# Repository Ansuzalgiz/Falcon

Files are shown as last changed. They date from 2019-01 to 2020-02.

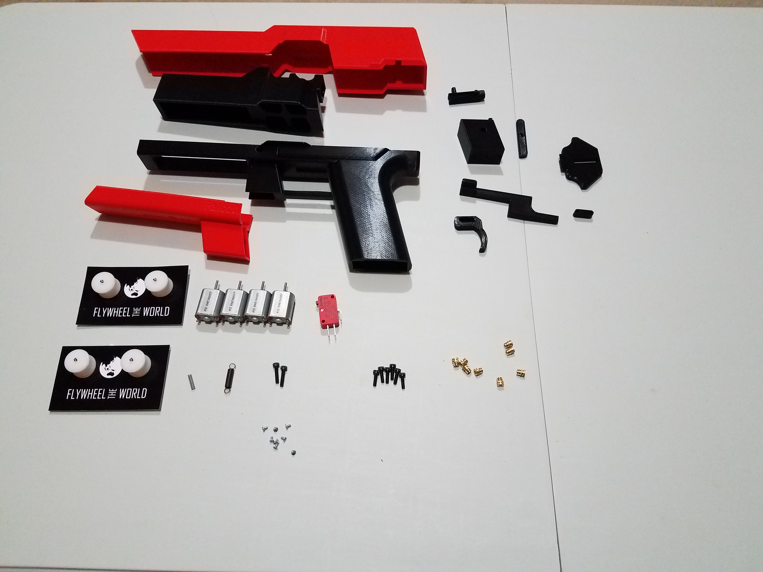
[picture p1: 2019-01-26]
Images/AllParts.jpg

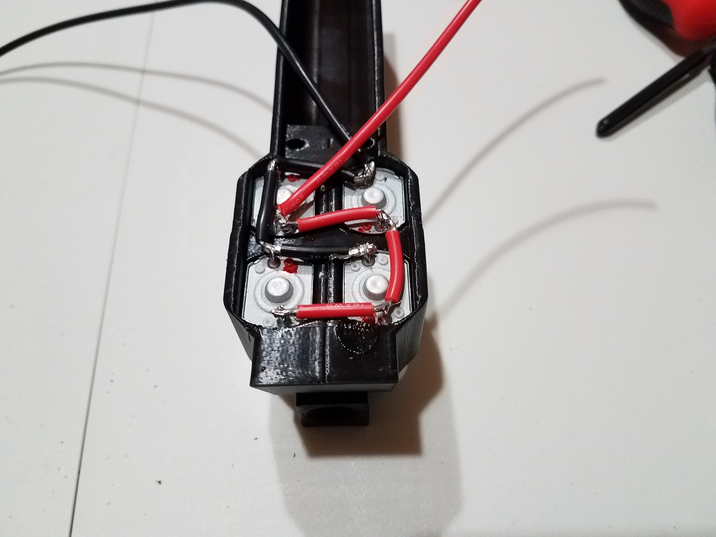
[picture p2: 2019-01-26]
Images/Wiring1.jpg

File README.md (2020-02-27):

# Falcon

The Falcon is a 3D printed semiautomatic Nerf pistol using Talon magazines.

# Features
- Dual stage flywheels using FTW flywheels
- Single trigger design
- Talon magazine compatibility
- Ambidextrous thumb actuated magazine release
- Optional builtin HOLDster mount

# Video Review

[Review by Drac](https://www.youtube.com/watch?v=akCXBWrKhHA)

# Online Availability
[Sold online on Etsy](https://www.etsy.com/shop/ansuzalgiz)

# Required Parts

|Part |Quantity  |Description |
|---|---|---|
|MTB Honeybadgers |4 |Flywheel Motors [Purchase link](https://outofdarts.com/collections/motors/products/mtb-honey-badger-130-motor-for-nerf-blasters) |
|FTW Flywheels |2 |Two sets of flywheels [Purchase link](https://blogderrikksun.com/product/mini-flywheels-set-for-pigeon-and-other-ftw-blasters/) |
|21A Microswitch  |1 |Flywheel switch [Purchase link](https://outofdarts.com/collections/parts/products/21a-microswitch-button-clone)|
|Heat set threaded inserts| 8 | To hold in screws (McMaster 94180A333 for 100) |
|Compression Spring | 1 | For magazine release (McMaster 9657K266 for 6) |
|Compression Spring | 1 | For trigger (McMaster 9657k297 for 12) |
|M3x14 Socket head screw  | 2 | For attaching PusherMount to lower receiver |
|M3x10 Socket head screws | 6 | For attaching all other parts |
|M2x4 screws | 8 | For motors |
|Silicone grease | | For trigger mechanism |
|M5x.08 tap | 1 | For finishing the HOLDster top cover for screwing in the Fidlock magnets |
|HOLDster Fidlock magnets | 1 pair | For HOLDster support [Purchase link](https://outofdarts.com/products/holdster-magnets)| 

# Printing Parameters
Prototypes were printed using these parameters:
- PLA
- 300 micron layer height
- .4mm nozzle
- No supports

# Contributing
The project was designed using Fusion 360, under their hobbyist license. After updating the design, export the changed STEP and STL files and use software like MeshMixer or 3D Builder to orient the STLs for printing.

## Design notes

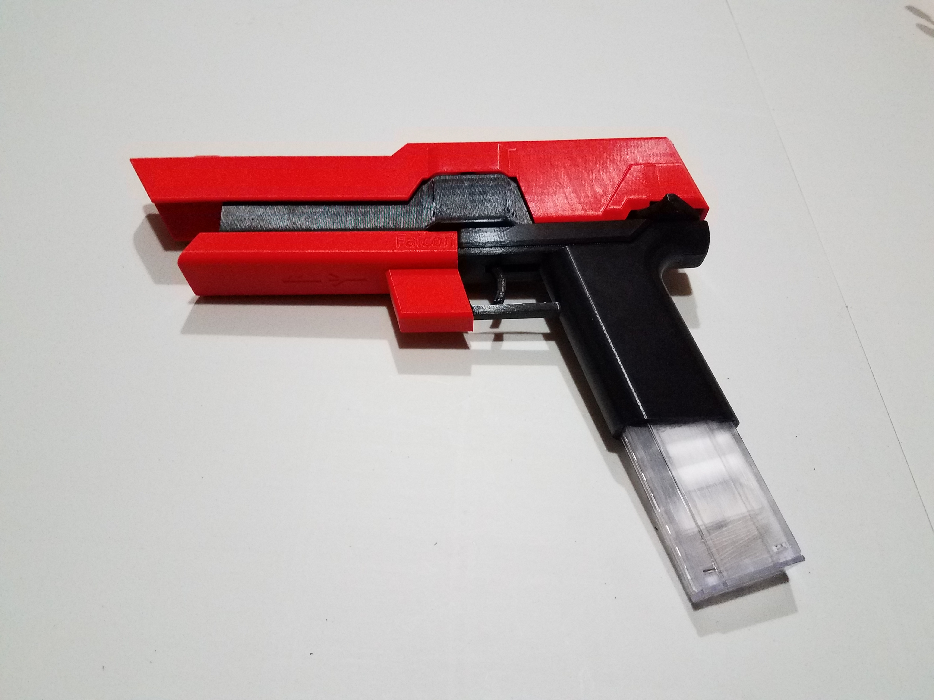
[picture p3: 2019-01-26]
Images/Finished.jpg

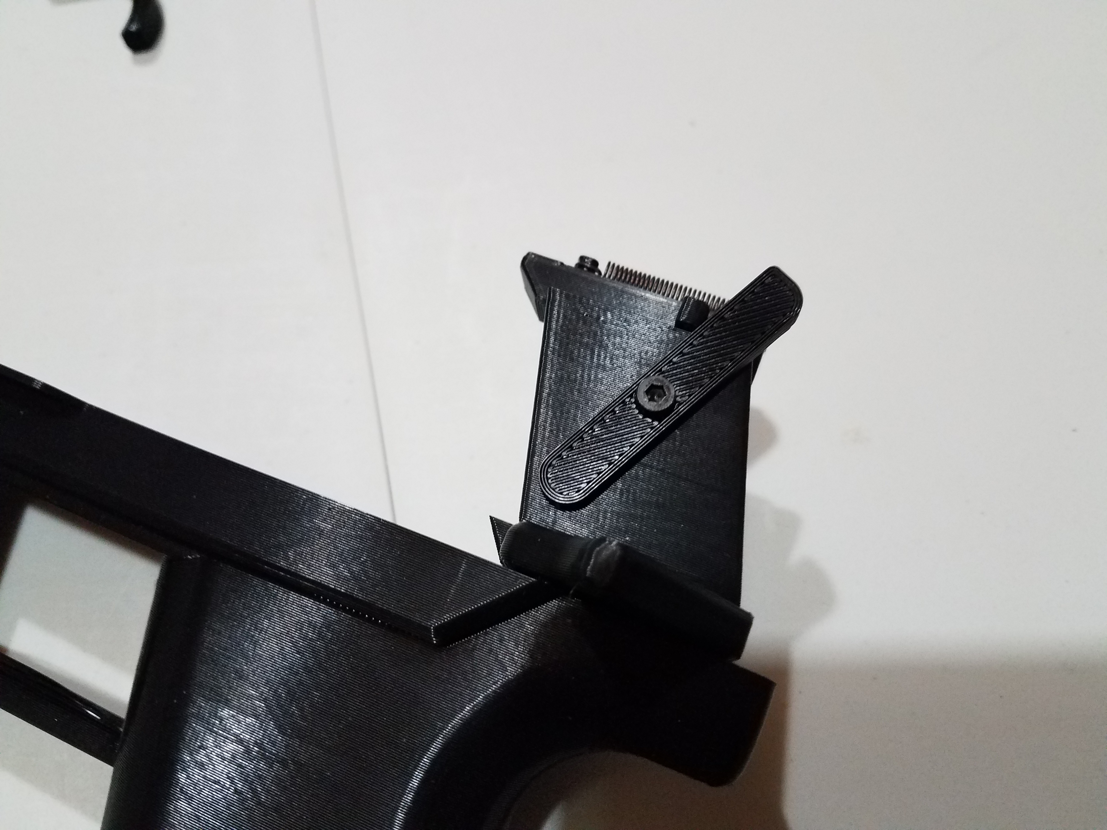
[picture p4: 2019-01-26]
Images/Pusher3.jpg

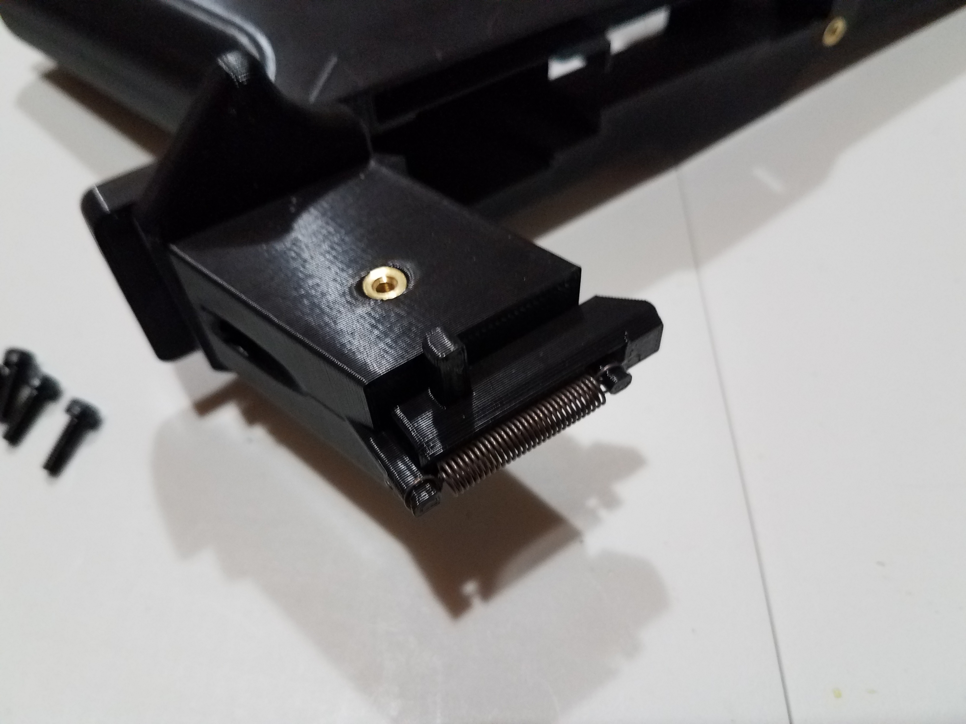
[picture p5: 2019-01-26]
Images/Pusher2.jpg

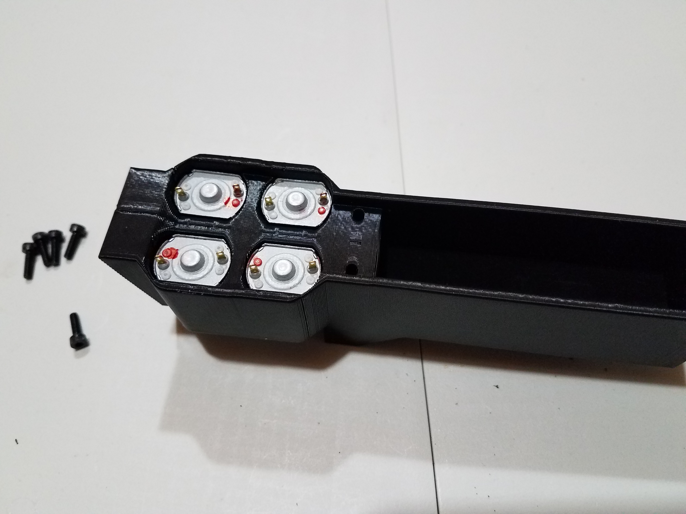
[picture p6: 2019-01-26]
Images/Motors1.jpg

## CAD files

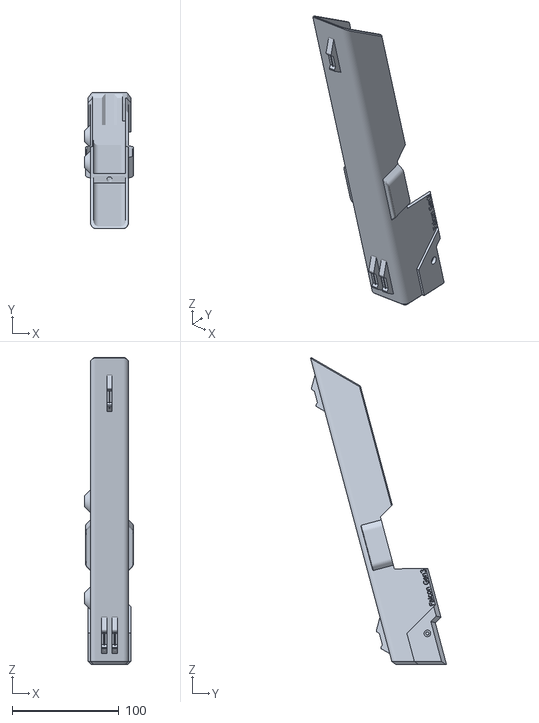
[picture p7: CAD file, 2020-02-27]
STLs/Accessories/HOLDsterCoverLeft.stl
46.0 x 127.7 x 288.2

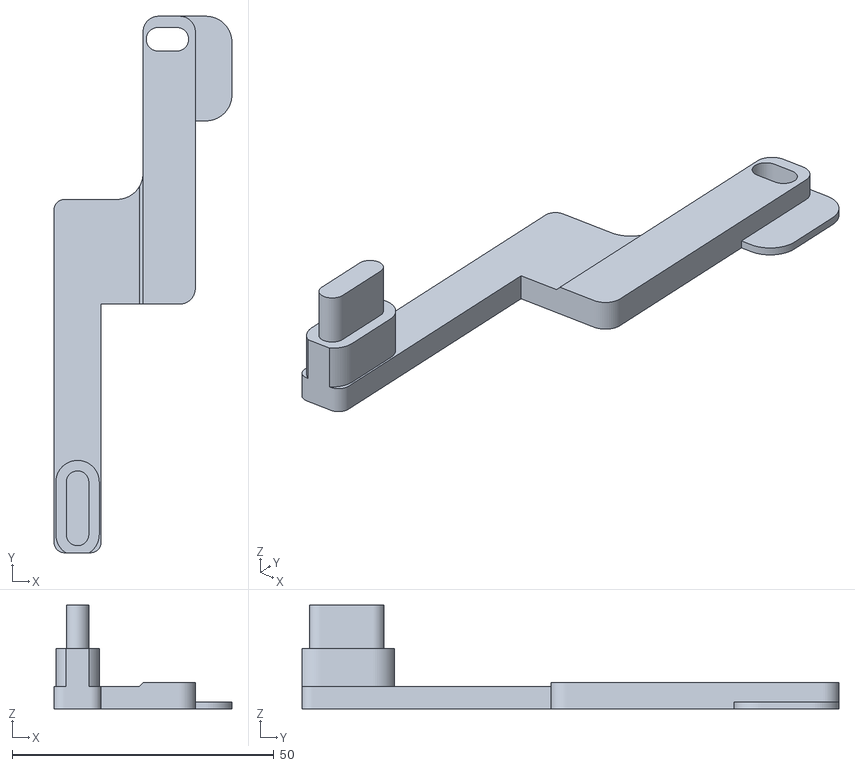
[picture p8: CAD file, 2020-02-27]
STLs/TriggerArmLeft.stl
34.0 x 102.5 x 19.8

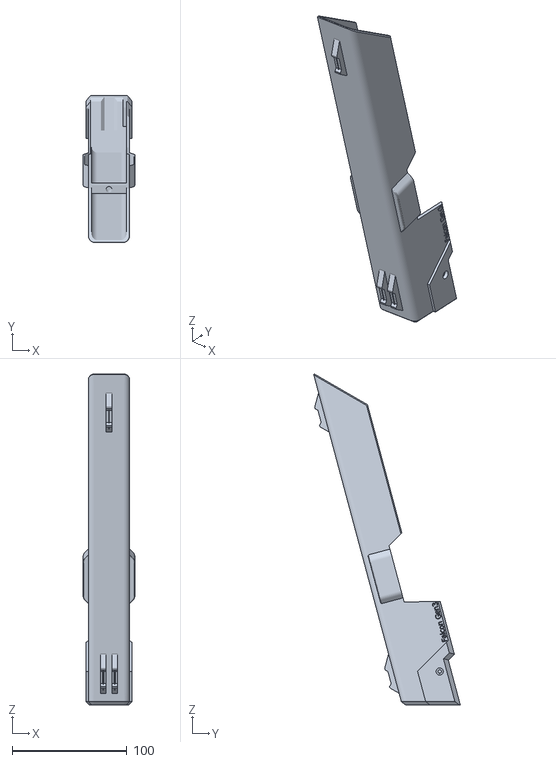
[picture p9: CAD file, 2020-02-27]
STLs/TopCover.stl
45.0 x 127.7 x 288.2

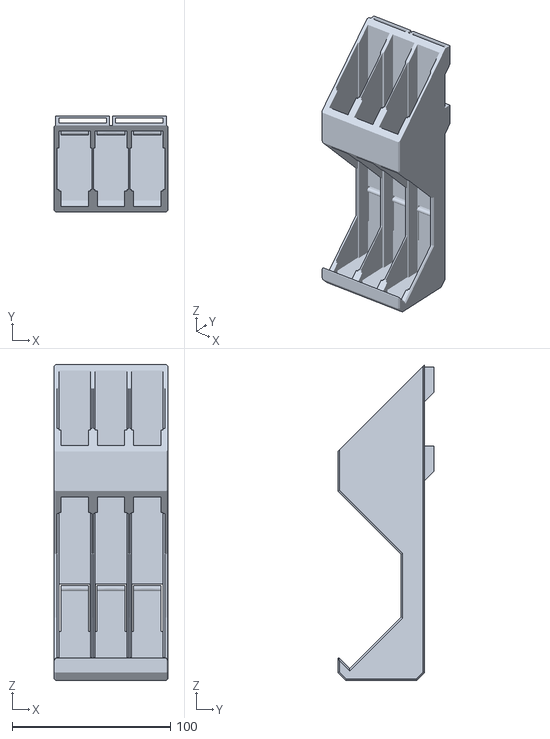
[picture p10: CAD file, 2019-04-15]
STLs/Accessories/3xTalonMagHolder.stl
72.0 x 61.0 x 200.0

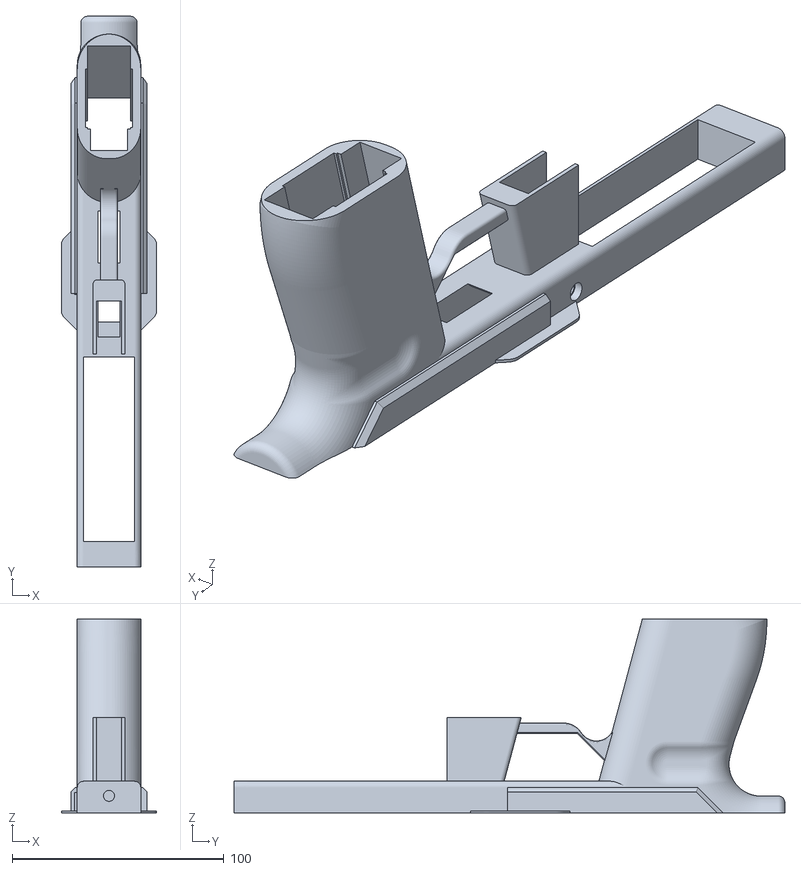
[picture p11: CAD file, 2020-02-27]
STLs/LowerReceiver.stl
45.0 x 260.0 x 91.6

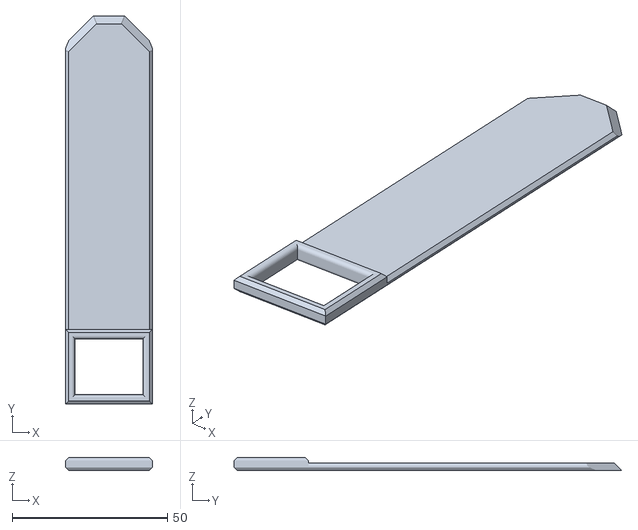
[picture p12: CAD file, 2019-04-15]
STLs/Accessories/MolleStrip.stl
28.0 x 125.0 x 4.25

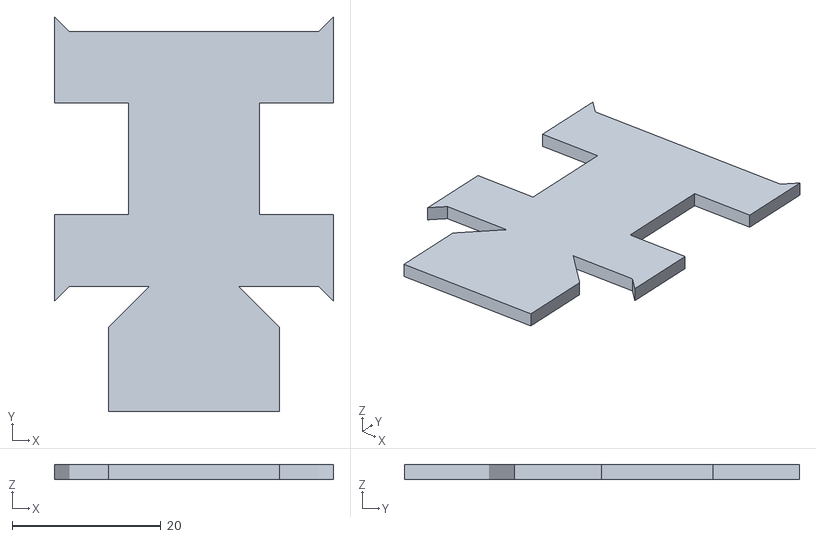
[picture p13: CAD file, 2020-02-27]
STLs/MotorSupportTool.stl
37.6 x 53.2 x 2.00

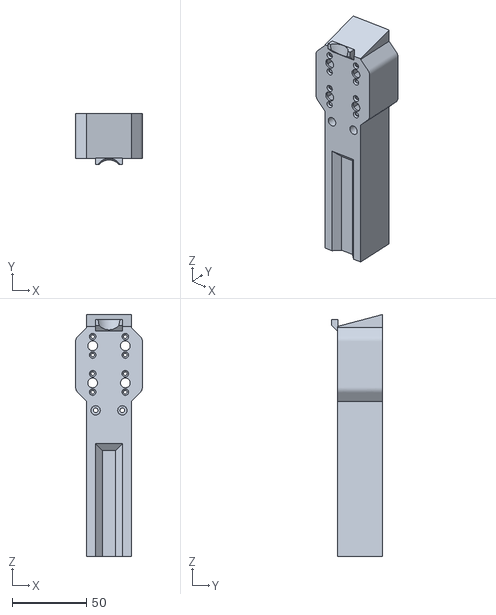
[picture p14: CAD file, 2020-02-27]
STLs/UpperReciever.stl
45.0 x 34.4 x 163.1

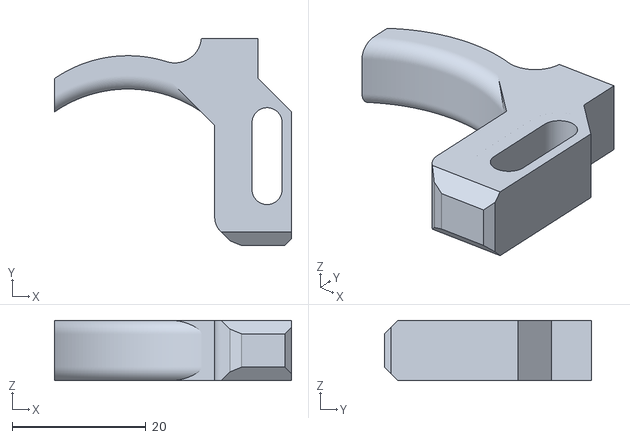
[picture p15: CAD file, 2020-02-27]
STLs/Trigger.stl
35.5 x 31.0 x 9.00

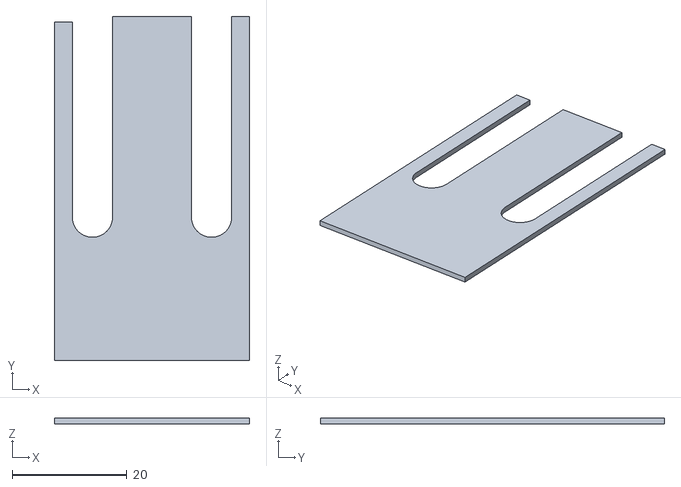
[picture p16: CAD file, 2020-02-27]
STLs/FlywheelShim.stl
34.0 x 60.0 x 1.00

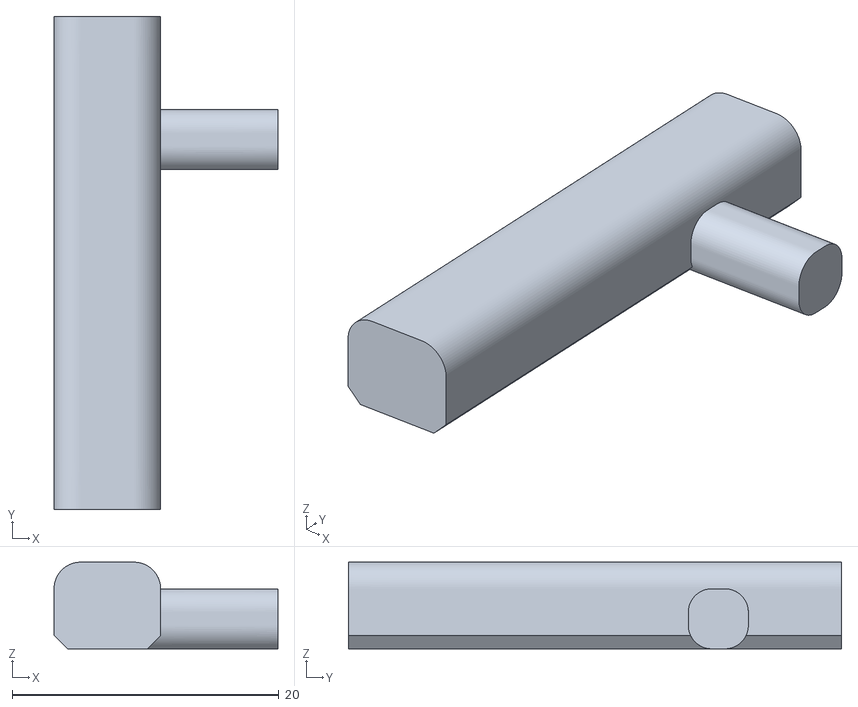
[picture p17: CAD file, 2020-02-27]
STLs/Pusher.stl
16.8 x 37.0 x 6.50

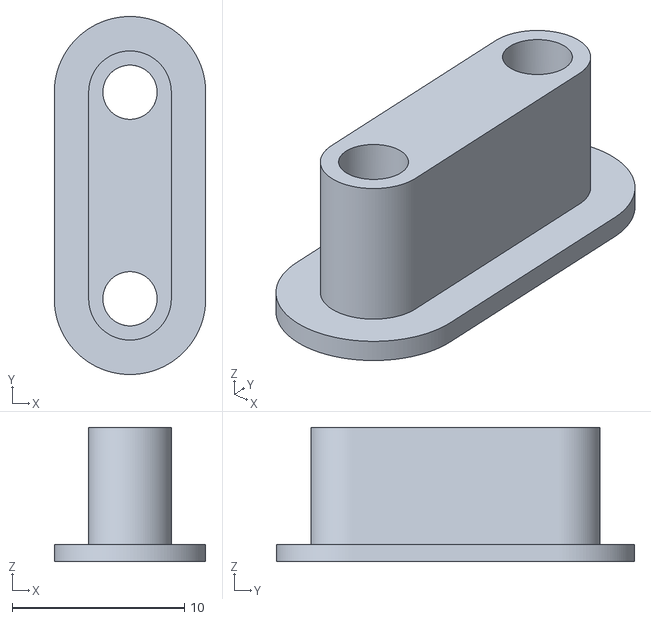
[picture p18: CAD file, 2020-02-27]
STLs/Spacer.stl
8.80 x 20.8 x 7.80

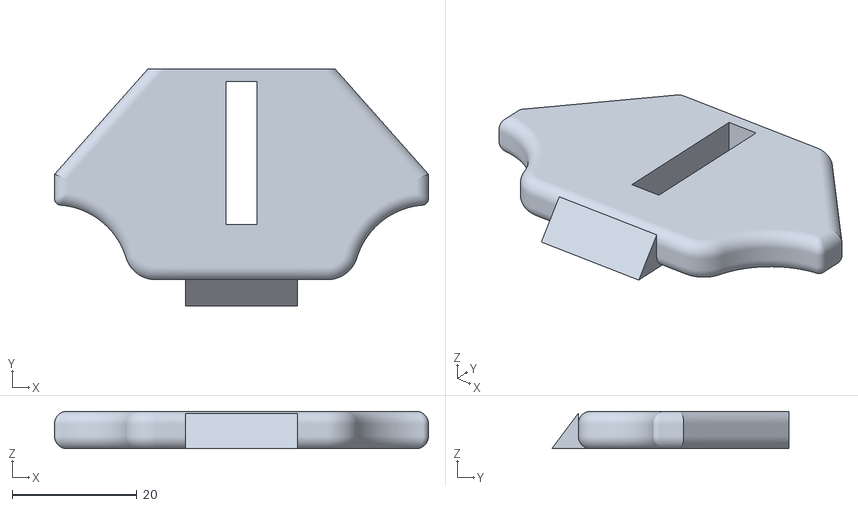
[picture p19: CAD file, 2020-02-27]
STLs/MagRelease.stl
60.0 x 38.1 x 6.00

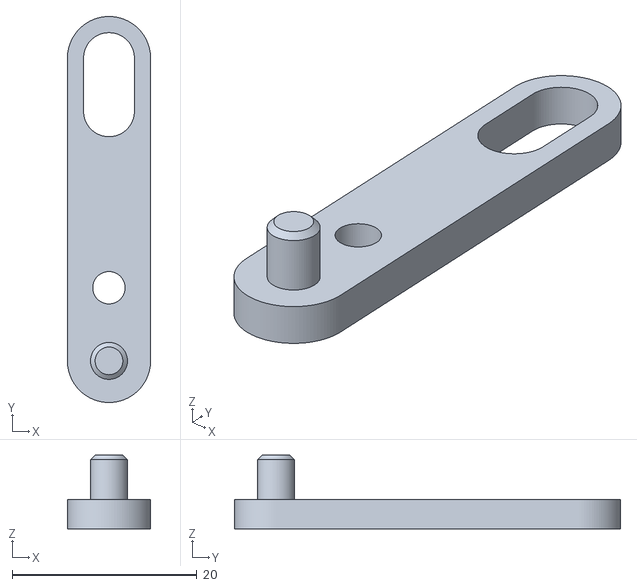
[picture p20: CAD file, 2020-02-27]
STLs/PusherLinkage.stl
9.00 x 41.8 x 8.00

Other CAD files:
STLs/Accessories/HOLDsterCoverRight.stl
STLs/BatteryCover.stl
STLs/FlaredMagwell.stl
STLs/PusherMount.stl

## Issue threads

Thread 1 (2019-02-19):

Pusher jam

Puredeathnight, 2019-02-19:
Ive found that the pusher binds on the pusher mount, from the torque of pushing/being pushed by the pusher arm. This binds the trigger halfway though the pull and keeps it from hitting the switch when released.

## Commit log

2019-01-26 Add single stage upper reciever
    Adding a single stage upper receiver, which reduces the build by $30 and 15FPS
    [UpperRecieverSingleStage.step, UpperRecieverSingleStage.stl]
2019-02-01 Fixes
    Increased clearance around flywheels. Added support structure on TopCover to secure front to UpperReceiver. Increased battery compartment size by enlarging BatterCover.
    [BatteryCover.step, BatteryCover.stl, TopCover.step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]
2019-04-06 Update covers for better fit and HOLDster support.
    Decreased diameter of screw hole of BatteryCover for a more secure hold.
    Made TopCover more secure on the blaster and added HOLDster support.
    [BatteryCover.step, BatteryCover.stl, FlywheelInstallatiionTool.step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]
2019-04-06 Update README.md
    Forgot HOLDster magnet link
2019-04-15 Added Talon mag holder
    [3xTalonMagHolder.stl, MolleStrip.stl]
2019-04-25 Update grip profile and move accessories to a subdirectory
    Moved the thumb rest higher to make pointing and aiming more intuitive.
    Move accessories to subdirectory to make them easier to consume
    [3xTalonMagHolder.stl, LowerReceiver.step, LowerReceiver.stl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]
2020-02-27 Updated Falcon to Gen3
    Gen2 updates focus on reliability and comfort. A dart guide was added to
    correct most of the dart entry angle during feed and severely improves
    reliabilit. The lower receiver was recontoured to provide better
    comfort.
    Gen3 removes the cage guide and streamlines the top cover to improve
    FPS.
    [BatteryCover.step, BatteryCover.stl, FTWFlywheels.step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]
